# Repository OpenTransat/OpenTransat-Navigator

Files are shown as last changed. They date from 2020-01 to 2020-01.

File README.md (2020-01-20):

# OpenTransat-Navigator
The brain of the boat responsible for navigation.

## Features

* Based on Atmega2560 @ 16 MHz

* Over-the-air programming using ESP8266 flashed with Wifi-serial bridge [esp-link](https://github.com/jeelabs/esp-link)

* 9-axis accelerometer / gyro / compass

* Voltage / current sensor

* 16 Mbit flash

* 2 Mbit FRAM

* Temperature / pressure / humidity sensor

* Serial multiplexer

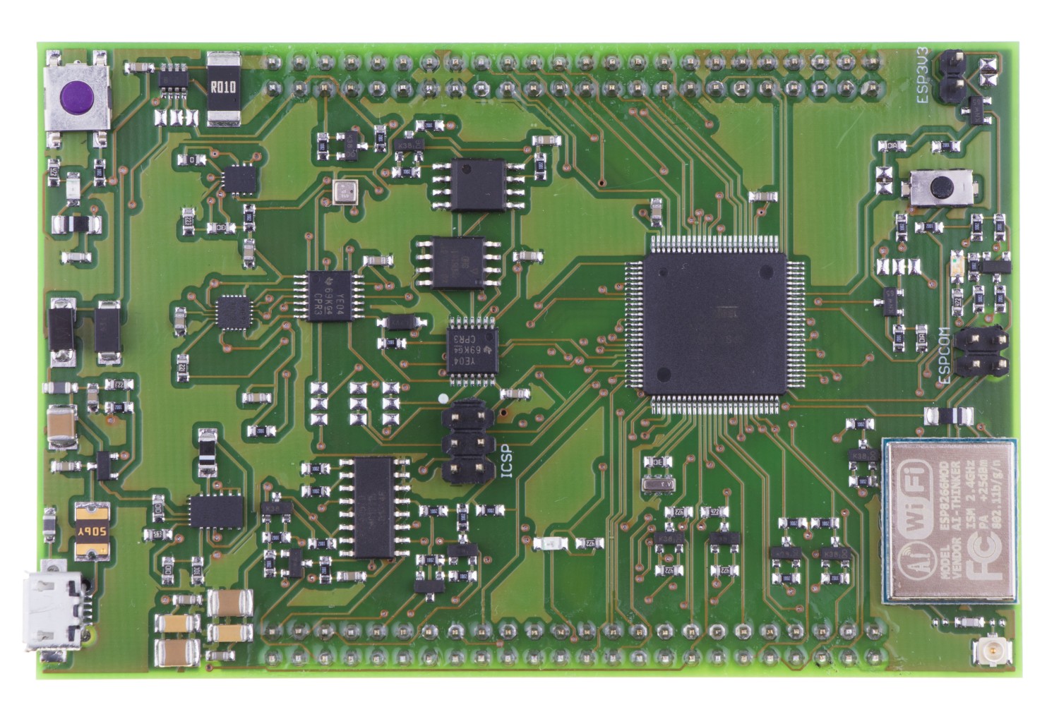
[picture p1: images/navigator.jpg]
Navigator PCB


## Boat Hardware Scheme

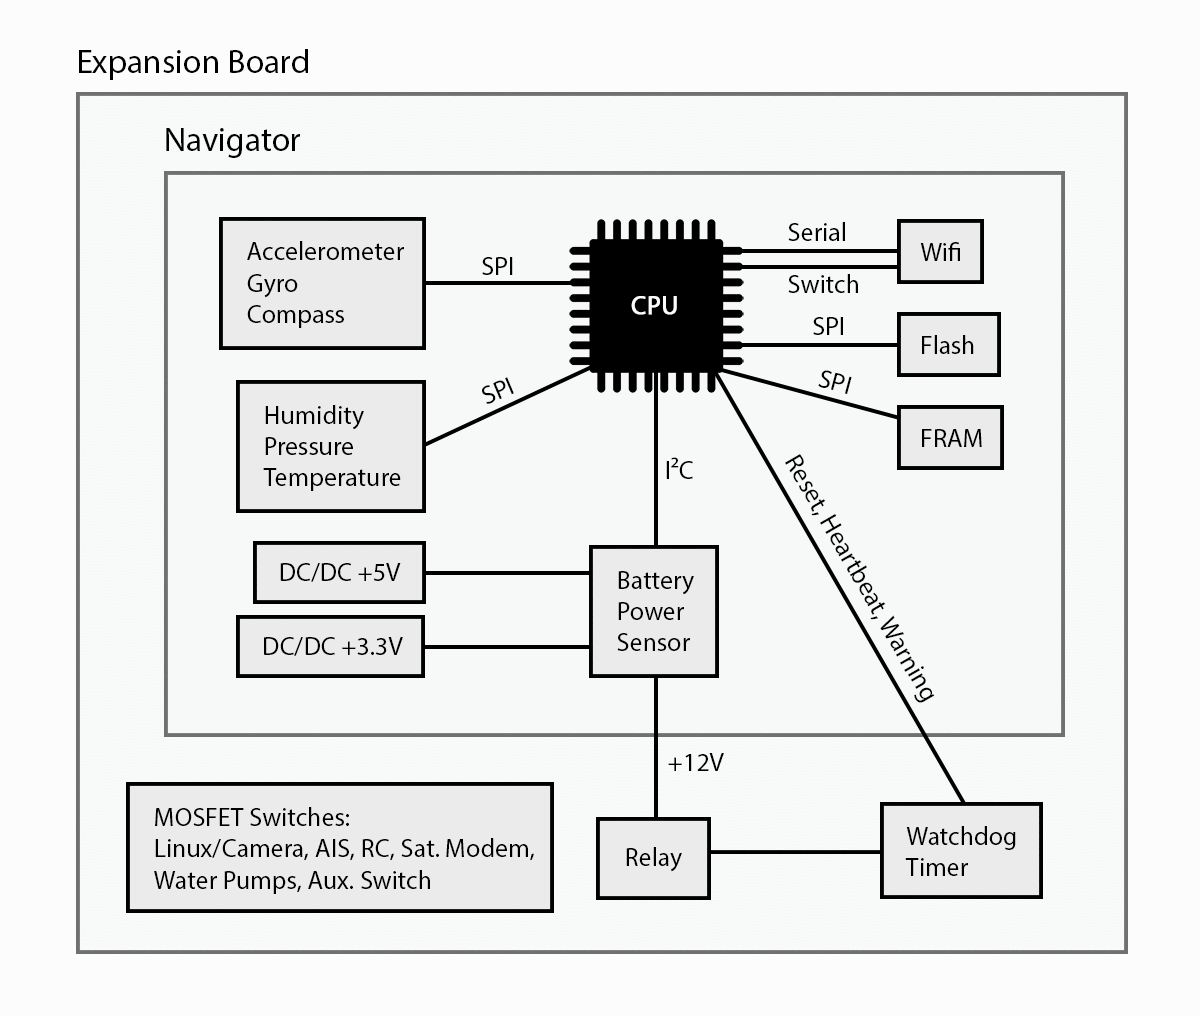
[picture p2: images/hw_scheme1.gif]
Boat Hardware Scheme


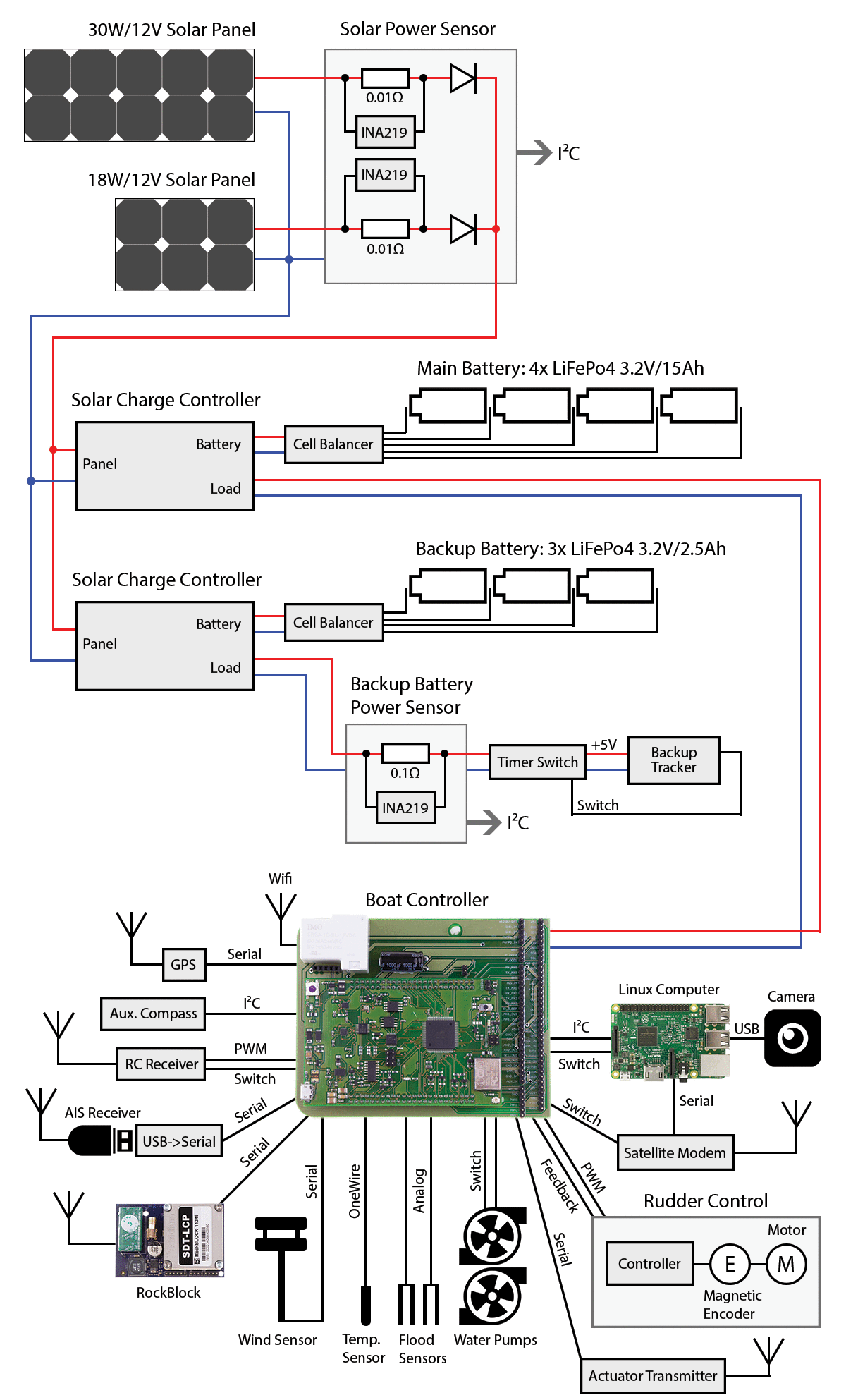
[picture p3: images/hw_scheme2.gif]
Boat Hardware Scheme


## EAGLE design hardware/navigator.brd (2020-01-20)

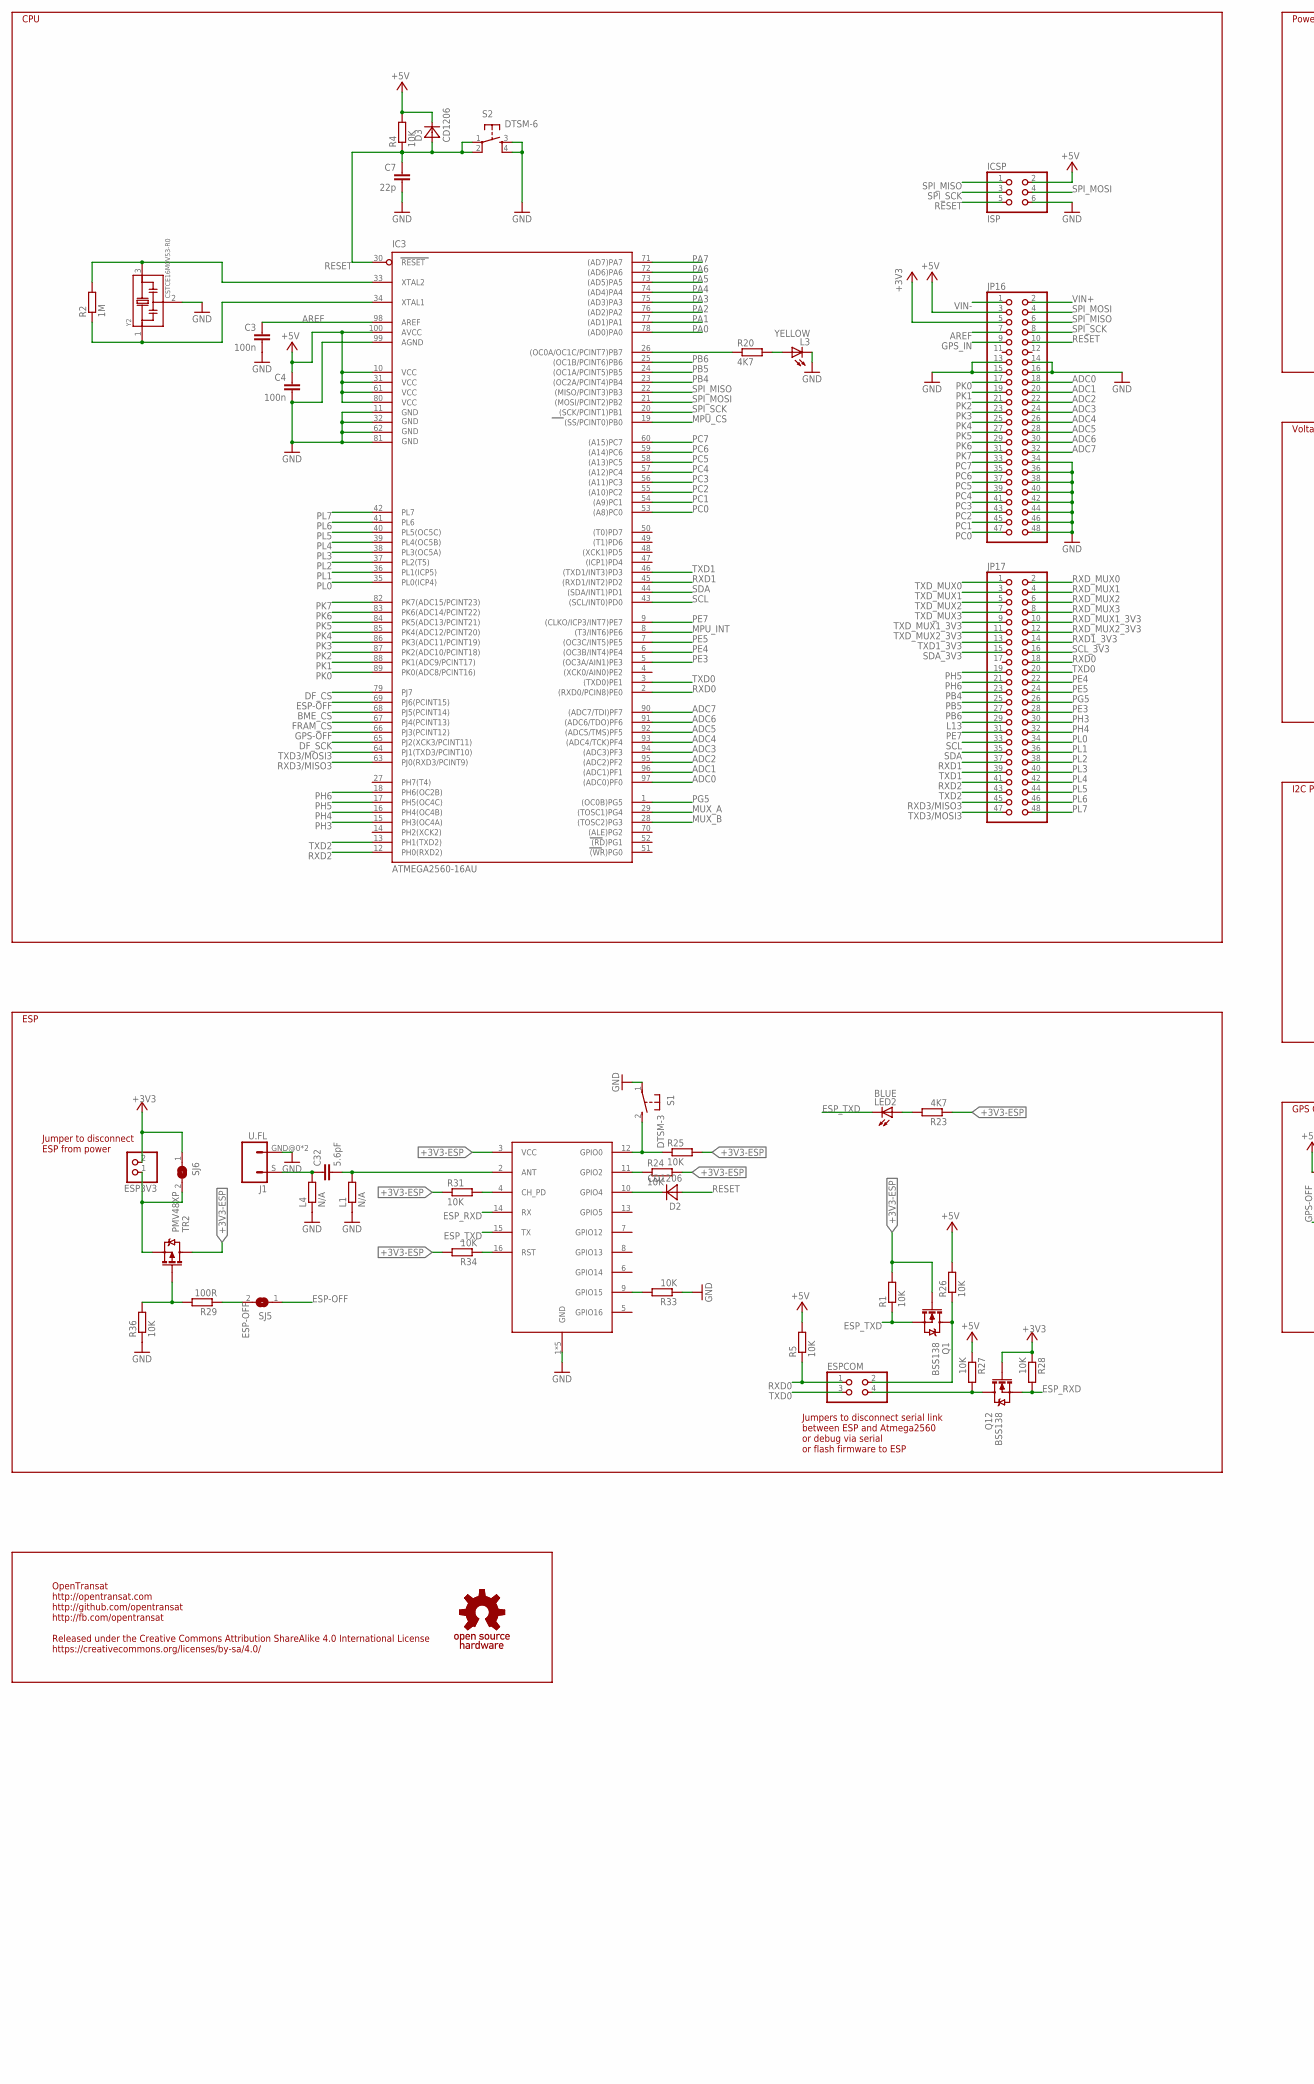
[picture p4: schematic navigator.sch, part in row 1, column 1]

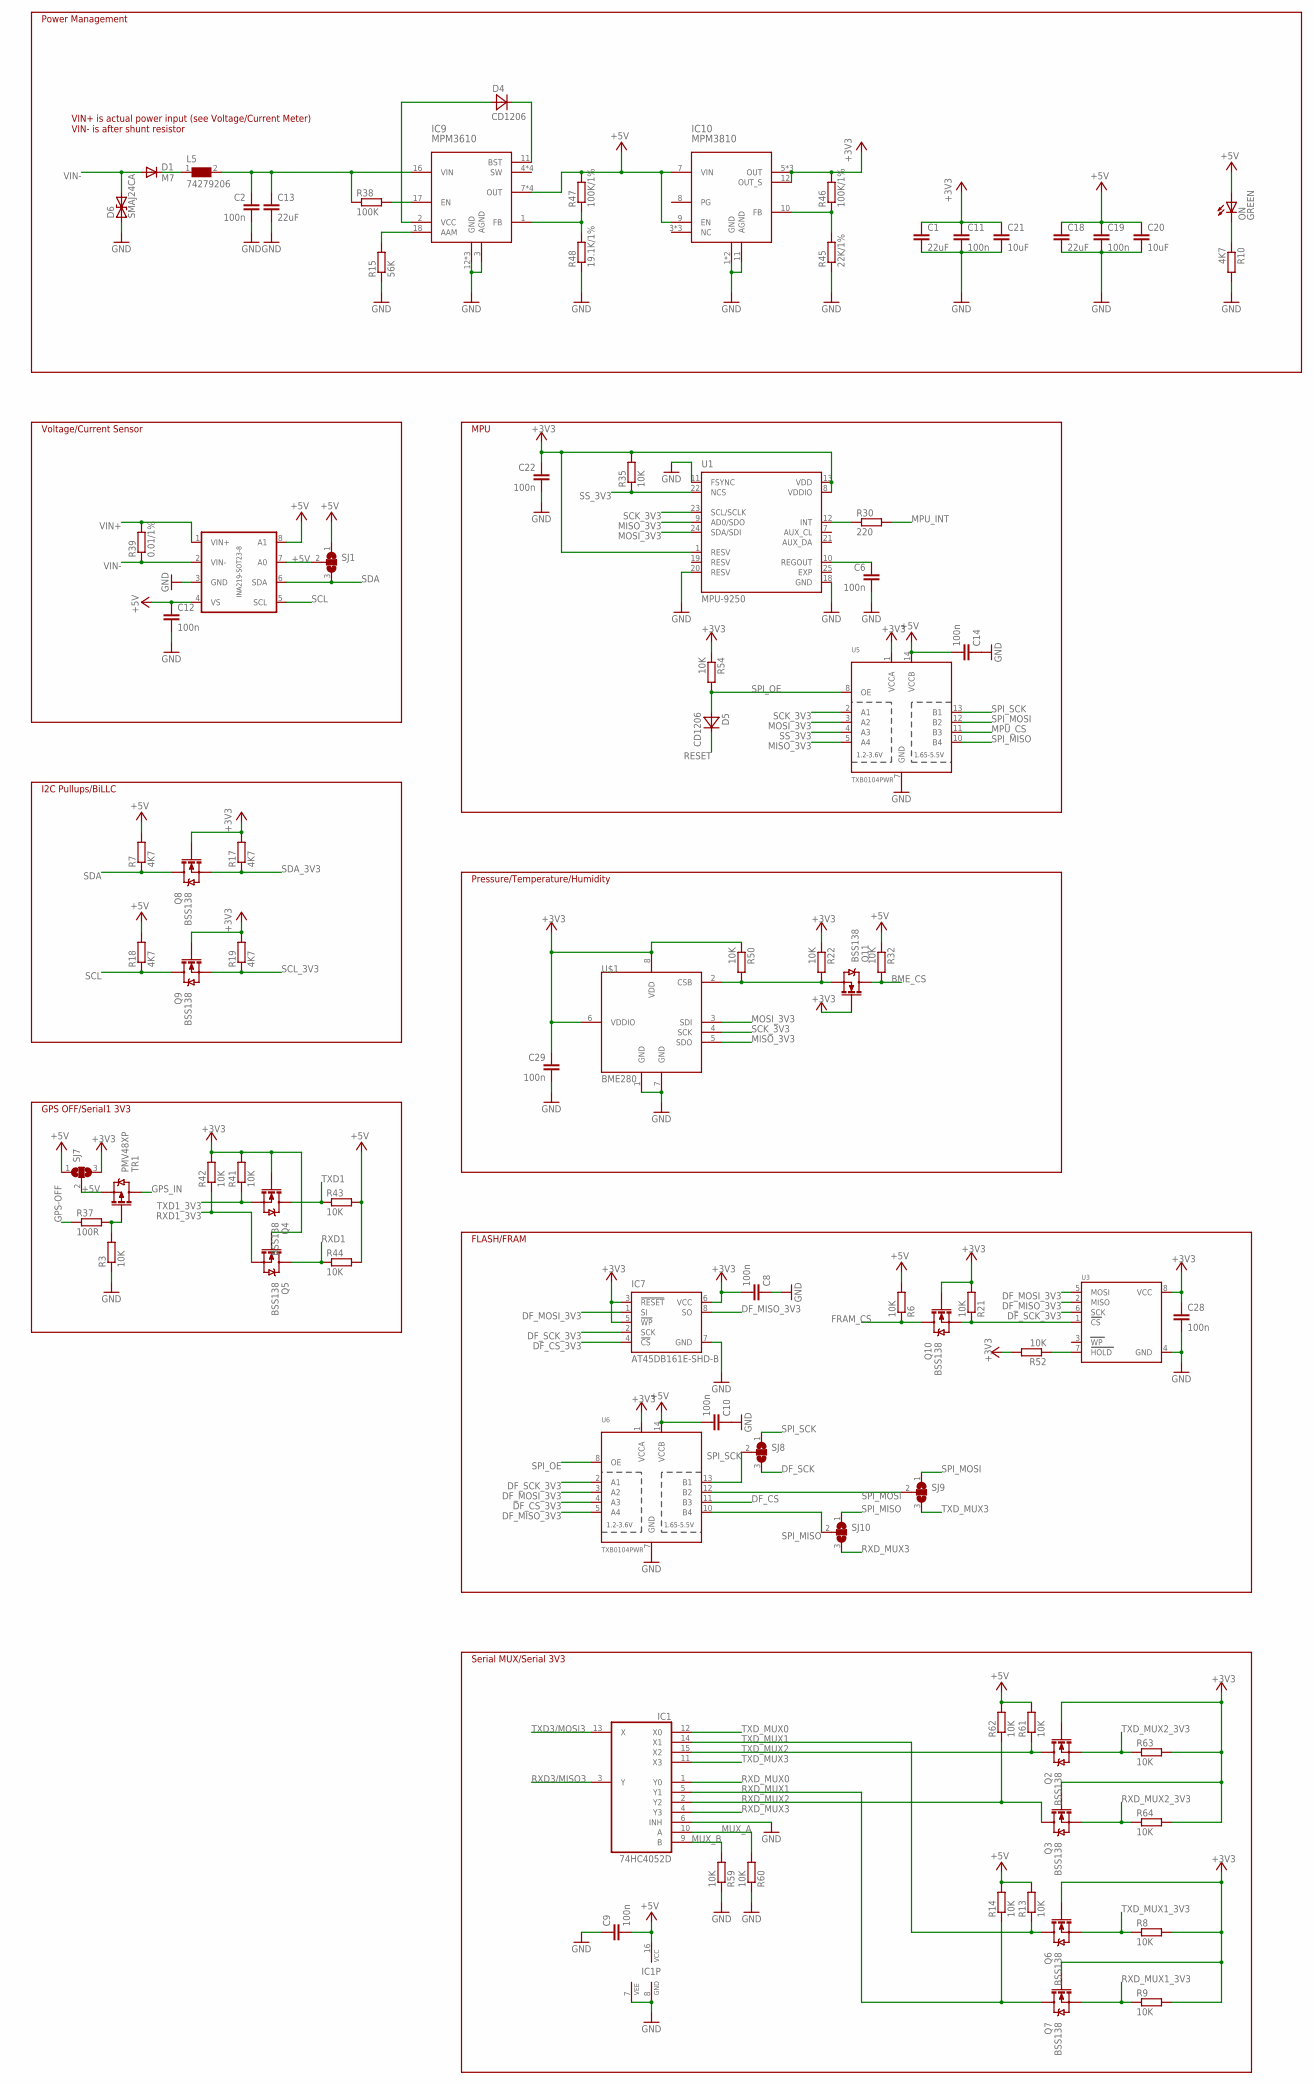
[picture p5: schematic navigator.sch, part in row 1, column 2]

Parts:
C1, C13, C18: 22uF; C1210
C2, C3, C4, C6, C8, C9, C10, C11, C12, C14, C19, C22, C28, C29: 100n; C0603
C7: 22p; C0603
C20, C21: 10uF; C1206
C32: 5.6pF; C0603
D1: M7; DO-214AC
D2, D3, D4, D5: CD1206; R1206
D6: SMAJ24CA; DO214AC
ESP3V3: PINHD-1X2; 1X02
ESPCOM: PINHD-2X2; 2X02
IC1: 74HC4052D; SO16
IC3: ATMEGA2560-16AU; TQFP100
IC7: AT45DB161E-SHD-B; 8S2
IC9: MPM3610; MPM_QFN20
IC10: MPM3810; MPM_QFN12
ICSP: ISP; 2X03
J1: U.FL; CON-U.FL
JP16, JP17: PINHD-2X24; 2X24
L1, L4: N/A; R0402
L3: YELLOW; CHIPLED_0805
L5: 74279206; 0805
LED2: BLUE; CHIPLED_0805
ON: GREEN; CHIPLED_0805
Q1, Q2, Q3, Q4, Q5, Q6, Q7, Q8, Q9, Q10, Q11, Q12: BSS138; SOT23-3
R1, R3, R4, R5, R6, R8, R9, R13, R14, R21, R22, R24, R25, R26, R27, R28, R31, R32, R33, R34, R35, R36, R41, R42, R43, R44, R50, R52, R54, R59, R60, R61, R62, R63, R64: 10K; R0603
R2: 1M; R0603
R7, R10, R17, R18, R19, R20, R23: 4K7; R0603
R15: 56K; R0603
R29, R37: 100R; R0603
R30: 220; R0603
R38: 100K; R0603
R39: 0.01/1%; R2512
R45: 22K/1%; R0603
R46, R47: 100K/1%; R0603
R48: 19.1K/1%; R0603
S1: DTSM-3
S2: DTSM-6
SJ1, SJ7, SJ8, SJ9, SJ10: SJ2W; SJ_2
SJ5, SJ6: SJ
TR1, TR2: PMV48XP; SOT23-3
U1: MPU-9250; QFN40P300X300X105-25N
U3: FRAM_SOIC8_200MIL_SPI; SOIC8_200MIL
U5, U6: TXB0104PWR; TSSOP14
U$1: BME280
U$2: ESP-06
U$3: INA219-SOT23-8; SOT23-8
U$4: OSHW; OSHWM
Y2: CSTCE16M0V53-R0; OSC_CSTCE16M0V53-R0

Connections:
+3V3: C1.1, C8.2, C11.1, C21.1, C22.1, C28.1, C29.1, ESP3V3.2, IC7.3 (!RESET), IC7.5 (!WP), IC7.6 (VCC), IC10.5 (OUT), IC10.6 (OUT), IC10.12 (OUT_S), IC10.14 (OUT), JP16.5, Q2.1 (G), Q3.1 (G), Q4.1 (G), Q5.1 (G), Q6.1 (G), Q7.1 (G), Q8.1 (G), Q9.1 (G), Q10.1 (G), Q11.1 (G), Q12.1 (G), R8.2, R9.2, R17.2, R19.2, R21.2, R22.1, R28.1, R35.2, R41.2, R42.2, R46.2, R50.1, R52.2, R54.1, R63.2, R64.2, SJ6.1, SJ7.3, U1.1 (RESV), U1.8 (VDDIO), U1.13 (VDD), U3.8 (VCC), U5.1 (VCCA), U6.1 (VCCA), U$1.6 (VDDIO), U$1.8 (VDD)
+3V3-ESP: Q1.1 (G), R1.2, R23.1, R24.2, R25.2, R31.1, R34.2, TR2.3 (D), U$2.3 (VCC)
+5V: C4.1, C9.2, C10.2, C12.1, C14.2, C18.1, C19.1, C20.1, D3.2 (C), IC1.16 (VCC), IC3.10 (VCC), IC3.31 (VCC1), IC3.61 (VCC2), IC3.80 (VCC3), IC3.100 (AVCC), IC9.7 (OUT), IC9.8 (OUT), IC9.9 (OUT), IC9.20 (OUT), IC10.7 (VIN), IC10.9 (EN), ICSP.2, JP16.3, ON.A, R4.2, R5.2, R6.2, R7.2, R13.2, R14.2, R18.2, R26.2, R27.1, R32.1, R43.2, R44.2, R47.2, R61.2, R62.2, SJ1.1, SJ1.2, SJ7.1, SJ7.2, TR1.2 (S), U5.14 (VCCB), U6.14 (VCCB), U$3.4 (VS), U$3.7 (A0), U$3.8 (A1)
ADC0: IC3.97 ((ADC0)PF0), JP16.18
ADC1: IC3.96 ((ADC1)PF1), JP16.20
ADC2: IC3.95 ((ADC2)PF2), JP16.22
ADC3: IC3.94 ((ADC3)PF3), JP16.24
ADC4: IC3.93 ((ADC4/TCK)PF4), JP16.26
ADC5: IC3.92 ((ADC5/TMS)PF5), JP16.28
ADC6: IC3.91 ((ADC6/TDO)PF6), JP16.30
ADC7: IC3.90 ((ADC7/TDI)PF7), JP16.32
AREF: C3.1, IC3.98 (AREF), JP16.7
BME_CS: IC3.68 (PJ5(PCINT14)), Q11.3 (D), R32.2
DF_CS: IC3.79 (PJ7), U6.11 (B3)
DF_CS_3V3: IC7.4 (!CS), U6.4 (A3)
DF_MISO_3V3: IC7.8 (SO), U3.2 (MISO), U6.5 (A4)
DF_MOSI_3V3: IC7.1 (SI), U3.5 (MOSI), U6.3 (A2)
DF_SCK: IC3.65 (PJ2(XCK3/PCINT11)), SJ8.3
DF_SCK_3V3: IC7.2 (SCK), U3.6 (SCK), U6.2 (A1)
ESP-OFF: IC3.69 (PJ6(PCINT15)), R29.1, SJ5.1, SJ5.2
ESP_RXD: Q12.2 (S), R28.2, U$2.14 (RX)
ESP_TXD: LED2.C, Q1.2 (S), R1.1, U$2.15 (TX)
EXP: U1.25 (EXP)
FRAM_CS: IC3.67 (PJ4(PCINT13)), Q10.3 (D), R6.1
GND: C1.2, C2.2, C3.2, C4.2, C6.2, C7.2, C8.1, C9.1, C10.1, C11.2, C12.2, C13.2, C14.1, C18.2, C19.2, C20.2, C21.2, C22.2, C28.2, C29.2, D6.A (1), IC1.6 (INH), IC1.7 (VEE), IC1.8 (GND), IC3.11 (GND), IC3.32 (GND1), IC3.62 (GND2), IC3.81 (GND3), IC3.99 (AGND), IC7.7 (GND), IC9.3 (AGND), IC9.12 (GND), IC9.13 (GND), IC9.14 (GND), IC10.1 (GND), IC10.2 (GND), IC10.11 (AGND), ICSP.6, J1.GND@0 (2), J1.GND@1 (2), JP16.13, JP16.14, JP16.15, JP16.16, JP16.34, JP16.36, JP16.38, JP16.40, JP16.42, JP16.44, JP16.46, JP16.48, L1.1, L3.C, L4.1, R3.1, R10.2, R15.1, R33.1, R36.1, R45.1, R48.1, R59.1, R60.1, S1.1, S2.3, S2.4, U1.11 (FSYNC), U1.18 (GND), U1.20 (RESV), U3.4 (GND), U5.7 (GND), U6.7 (GND), U$1.1 (GND), U$1.7 (GND), U$2.1 (GND), U$2.17 (GND), U$2.18 (GND), U$2.19 (GND), U$2.20 (GND), U$3.3 (GND), Y2.2
GPS-OFF: IC3.66 (PJ3(PCINT12)), R37.1
GPS_IN: JP16.9, TR1.3 (D)
L13: IC3.26 ((OC0A/OC1C/PCINT7)PB7), JP17.29, R20.1
MISO_3V3: U1.9 (AD0/SDO), U5.5 (A4), U$1.5 (SDO)
MOSI_3V3: U1.24 (SDA/SDI), U5.3 (A2), U$1.3 (SDI)
MPU_CS: IC3.19 ((SS/PCINT0)PB0), U5.11 (B3)
MPU_INT: IC3.8 ((T3/INT6)PE6), R30.2
MUX_A: IC1.10 (A), IC3.29 ((TOSC1)PG4), R60.2
MUX_B: IC1.9 (B), IC3.28 ((TOSC2)PG3), R59.2
unnamed: ESP3V3.1, SJ6.2, TR2.2 (S)
unnamed: R52.1, U3.7 (HOLD)
unnamed: ON.C, R10.1
unnamed: L3.A, R20.2
unnamed: D4.1 (A), IC9.2 (VCC)
unnamed: D4.2 (C), IC9.11 (BST)
unnamed: LED2.A, R23.2
unnamed: R31.2, U$2.4 (CH_PD)
unnamed: R24.1, U$2.11 (GPIO2)
unnamed: D2.2 (C), U$2.10 (GPIO4)
unnamed: R33.2, U$2.9 (GPIO15)
unnamed: C32.1, J1.S (1), L4.2
unnamed: R25.1, S1.2, U$2.12 (GPIO0)
unnamed: R34.1, U$2.16 (RST)
unnamed: C32.2, L1.2, U$2.2 (ANT)
unnamed: Q10.2 (S), R21.1, U3.1 (CS)
unnamed: IC10.10 (FB), R45.2, R46.1
unnamed: ESPCOM.2, Q1.3 (D), R26.1
unnamed: ESPCOM.4, Q12.3 (D), R27.2
unnamed: R3.2, R37.2, TR1.1 (G)
unnamed: R29.2, R36.2, TR2.1 (G)
unnamed: IC9.1 (FB), R47.1, R48.2
unnamed: IC9.17 (EN), R38.2
unnamed: IC9.18 (AAM), R15.2
unnamed: Q11.2 (S), R22.2, R50.2, U$1.2 (CSB)
unnamed: R30.1, U1.12 (INT)
PA0: IC3.78 ((AD0)PA0)
PA1: IC3.77 ((AD1)PA1)
PA2: IC3.76 ((AD2)PA2)
PA3: IC3.75 ((AD3)PA3)
PA4: IC3.74 ((AD4)PA4)
PA5: IC3.73 ((AD5)PA5)
PA6: IC3.72 ((AD6)PA6)
PA7: IC3.71 ((AD7)PA7)
PB4: IC3.23 ((OC2A/PCINT4)PB4), JP17.23
PB5: IC3.24 ((OC1A/PCINT5)PB5), JP17.25
PB6: IC3.25 ((OC1B/PCINT6)PB6), JP17.27
PC0: IC3.53 ((A8)PC0), JP16.47
PC1: IC3.54 ((A9)PC1), JP16.45
PC2: IC3.55 ((A10)PC2), JP16.43
PC3: IC3.56 ((A11)PC3), JP16.41
PC4: IC3.57 ((A12)PC4), JP16.39
PC5: IC3.58 ((A13)PC5), JP16.37
PC6: IC3.59 ((A14)PC6), JP16.35
PC7: IC3.60 ((A15)PC7), JP16.33
PE3: IC3.5 ((OC3A/AIN1)PE3), JP17.28
PE4: IC3.6 ((OC3B/INT4)PE4), JP17.22
PE5: IC3.7 ((OC3C/INT5)PE5), JP17.24
PE7: IC3.9 ((CLKO/ICP3/INT7)PE7), JP17.31
PG5: IC3.1 ((OC0B)PG5), JP17.26
PH3: IC3.15 (PH3(OC4A)), JP17.30
PH4: IC3.16 (PH4(OC4B)), JP17.32
PH5: IC3.17 (PH5(OC4C)), JP17.19
PH6: IC3.18 (PH6(OC2B)), JP17.21
PK0: IC3.89 (PK0(ADC8/PCINT16)), JP16.17
PK1: IC3.88 (PK1(ADC9/PCINT17)), JP16.19
PK2: IC3.87 (PK2(ADC10/PCINT18)), JP16.21
PK3: IC3.86 (PK3(ADC11/PCINT19)), JP16.23
PK4: IC3.85 (PK4(ADC12/PCINT20)), JP16.25
PK5: IC3.84 (PK5(ADC13/PCINT21)), JP16.27
PK6: IC3.83 (PK6(ADC14/PCINT22)), JP16.29
PK7: IC3.82 (PK7(ADC15/PCINT23)), JP16.31
PL0: IC3.35 (PL0(ICP4)), JP17.34
PL1: IC3.36 (PL1(ICP5)), JP17.36
PL2: IC3.37 (PL2(T5)), JP17.38
PL3: IC3.38 (PL3(OC5A)), JP17.40
PL4: IC3.39 (PL4(OC5B)), JP17.42
PL5: IC3.40 (PL5(OC5C)), JP17.44
PL6: IC3.41 (PL6), JP17.46
PL7: IC3.42 (PL7), JP17.48
PWRIN2: D1.C, L5.1
REGOUT: C6.1, U1.10 (REGOUT)
RESET: C7.1, D2.1 (A), D3.1 (A), D5.2 (C), IC3.30 (RESET), ICSP.5, JP16.10, R4.1, S2.1, S2.2
RESV: U1.19 (RESV)
RXD0: ESPCOM.1, IC3.2 ((RXD0/PCIN8)PE0), JP17.18, R5.1
RXD1: IC3.45 ((RXD1/INT2)PD2), JP17.37, Q5.3 (D), R44.1
RXD1_3V3: JP17.14, Q5.2 (S), R42.1
RXD2: IC3.12 (PH0(RXD2)), JP17.41
RXD3/MISO3: IC1.3 (Y), IC3.63 (PJ0(RXD3/PCINT9)), JP17.45
RXD_MUX0: IC1.1 (Y0), JP17.2
RXD_MUX1: IC1.5 (Y1), JP17.4, Q7.3 (D), R14.1
RXD_MUX1_3V3: JP17.10, Q7.2 (S), R9.1
RXD_MUX2: IC1.2 (Y2), JP17.6, Q3.3 (D), R62.1
RXD_MUX2_3V3: JP17.12, Q3.2 (S), R64.1
RXD_MUX3: IC1.4 (Y3), JP17.8, SJ10.3
SCK_3V3: U1.23 (SCL/SCLK), U5.2 (A1), U$1.4 (SCK)
SCL: IC3.43 ((SCL/INT0)PD0), JP17.33, Q9.3 (D), R18.1, U$3.5 (SCL)
SCL_3V3: JP17.16, Q9.2 (S), R19.1
SDA: IC3.44 ((SDA/INT1)PD1), JP17.35, Q8.3 (D), R7.1, SJ1.3, U$3.6 (SDA)
SDA_3V3: JP17.15, Q8.2 (S), R17.1
SPI_MISO: IC3.22 ((MISO/PCINT3)PB3), ICSP.1, JP16.6, SJ10.1, SJ10.2, U5.10 (B4), U6.10 (B4)
SPI_MOSI: IC3.21 ((MOSI/PCINT2)PB2), ICSP.4, JP16.4, SJ9.1, SJ9.2, U5.12 (B2), U6.12 (B2)
SPI_OE: D5.1 (A), R54.2, U5.8 (OE), U6.8 (OE)
SPI_SCK: IC3.20 ((SCK/PCINT1)PB1), ICSP.3, JP16.8, SJ8.1, SJ8.2, U5.13 (B1), U6.13 (B1)
SS_3V3: R35.1, U1.22 (NCS), U5.4 (A3)
TXD0: ESPCOM.3, IC3.3 ((TXD0)PE1), JP17.20
TXD1: IC3.46 ((TXD1/INT3)PD3), JP17.39, Q4.3 (D), R43.1
TXD1_3V3: JP17.13, Q4.2 (S), R41.1
TXD2: IC3.13 (PH1(TXD2)), JP17.43
TXD3/MOSI3: IC1.13 (X), IC3.64 (PJ1(TXD3/PCINT10)), JP17.47
TXD_MUX0: IC1.12 (X0), JP17.1
TXD_MUX1: IC1.14 (X1), JP17.3, Q6.3 (D), R13.1
TXD_MUX1_3V3: JP17.9, Q6.2 (S), R8.1
TXD_MUX2: IC1.15 (X2), JP17.5, Q2.3 (D), R61.1
TXD_MUX2_3V3: JP17.11, Q2.2 (S), R63.1
TXD_MUX3: IC1.11 (X3), JP17.7, SJ9.3
VIN: C2.1, C13.1, IC9.16 (VIN), L5.2, R38.1
VIN+: JP16.2, R39.2, U$3.1 (VIN+)
VIN-: D1.A, D6.C (2), JP16.1, R39.1, U$3.2 (VIN-)
XTAL1: IC3.34 (XTAL1), R2.1, Y2.1
XTAL2: IC3.33 (XTAL2), R2.2, Y2.3

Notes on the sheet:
Serial MUX/Serial 3V3
Voltage/Current Sensor
GPS OFF/Serial1 3V3
FLASH/FRAM
MPU
Pressure/Temperature/Humidity
ESP
CPU
Power Management
I2C Pullups/BiLLC
VIN+ is actual power input (see Voltage/Current Meter) VIN- is after shunt resistor
OpenTransat http://opentransat.com http://github.com/opentransat http://fb.com/opentransat Released under the Creative Commons Attribution ShareAlike 4.0 International License https://creativecommons.org/licenses/by-sa/4.0/
Jumper to disconnect ESP from power
Jumpers to disconnect serial link between ESP and Atmega2560 or debug via serial or flash firmware to ESP

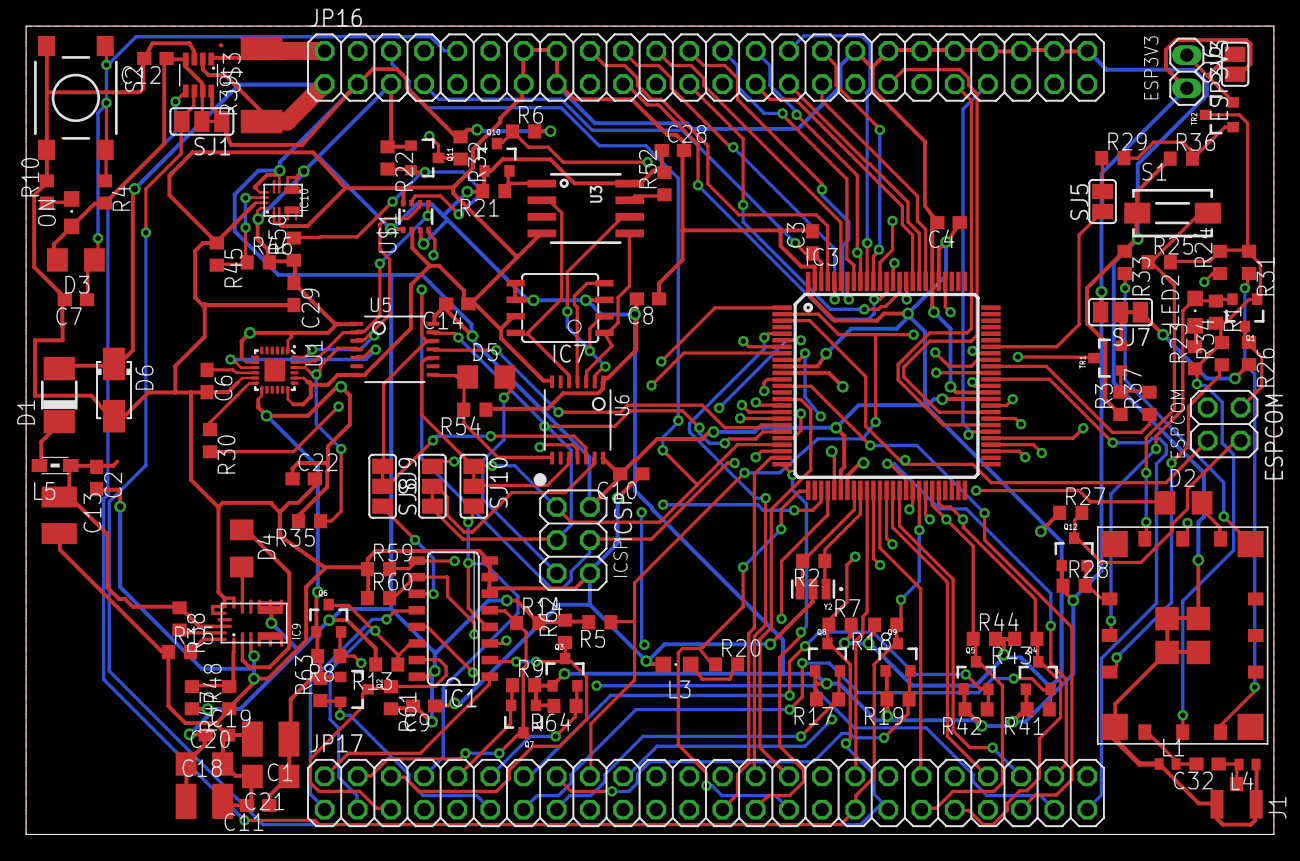
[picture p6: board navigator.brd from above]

Board: 4 copper layers, 95.6 x 61.9 mm, 129 parts (0 on the bottom side), 135 nets.

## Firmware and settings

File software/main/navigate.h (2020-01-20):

#define NAVMODE_MANUAL 0
#define NAVMODE_RUDDER_AUTO 1
#define NAVMODE_FLAP_AUTO 2
#define NAVMODE_FULLY_AUTO 3

#define TACKMODE_DIRECTLY 0
#define TACKMODE_ADJ_POS 1
#define TACKMODE_ADJ_NEG 2
#define TACKMODE_MAXDEV_POS 3
#define TACKMODE_MAXDEV_NEG 4

#define DEFAULT_RUDDER_COEFF 40
#define DEFAULT_RUDDER_PAUSE_SEC 2 //in seconds
#define RUDDER_MIN_ANGLE -25
#define RUDDER_MAX_ANGLE 25

#define HEADING_OK_LIMIT 7 //in degs

#define FLAP_MAX 16
#define FLAP_NORMAL 10
#define TACK_SAIL_CRITICAL_ANGLE 7
#define WIND_CONFIRMATION_SEC 3

//Earth mean radius
#define R_MEAN 6371000.0 //meters

//how often the magnetic declination is updated
#define MAGDEC_UPDATE_DISTANCE 100000.0 //meters
#define INTENSIVE_TASKS_INTERVAL 30000UL //30sec (function lasts: 14ms)

//#define ACT_MUST_WAIT_FROM_LNG -52.8943 //prevent waiting during launch //not used, rather use LAUNCH_DATE
#define ACT_LAUNCH_DATE 80719UL //MMDDYYUL, no leading zero

struct Location {
  double lat;
  double lng;
};

struct {
  unsigned char mode = NAVMODE_FULLY_AUTO;
  unsigned char tackmode = TACKMODE_DIRECTLY;
  Location gps;
  float magDec; //in degs
  bool magDecInitialized = false; //magDec is initialized based on valid gps location before the boat can navigate
  bool intensiveTasks_initialized = false; //ghostPoint must be calculated before the boat can navigate
  bool ghostHeadingInitialized = false; //ghostHeading must be calculated before the boat can navigate
  Location magDec_loc; //last location where magDec was calculated
  bool IR_doTransmit = false; //this flag is set to true in Iridium interval and transmitting starts in the navigate(..) function when the rudder is idle for a moment
  int trueHeading; //compass yaw + magnetic declination
  int trueWind; //trueHeading + relative wind
  Location closestPoint;
  Location ghostPoint;
  double crossTrack;
  double alongTrack;
  int ghostHeading_instant; //heading to the ghostPoint
  int ghostHeading; //heading to the ghostPoint (if headingOK())
  int goHeading; //in degs, where to go
  int pathAngle; //path bearing at closestPoint
  bool isBehindPath;
  int error; //in degs
  int flap;
  int sail_angle;
  int rudder_angle = 0; //must be remembered after the navigate() iteration
  bool rudderAgainstWind; //if the default turning is against the wind
  bool IR_transmit = false;
  unsigned long intensive_ms = 0;
  unsigned long nonIntensive_micros = 0;
  char wind_confirmation_sec = WIND_CONFIRMATION_SEC;
} nav;

struct TadjustedAngles {
  bool canGoDirectly;
  int adjAngle1;
  int adjAngle2;
};

struct TbestAdjHeading {
  int heading;
  unsigned char tackmode;
};

//location with radius[meters]; waypoint is considered to be reached within the radius, boat is heading to the ghostPoint at ghostDistance and special consideration is taken if max deviation from the main path is reached
struct waypoint {
  Location loc;
  double radius;
  double ghostDistance;
  double maxDev;
};

#define MAXDEV_OK_FACTOR 0.75

//Newfoundland -> waypoint on finish line -> Brest
//set of waypoints
#define WAYPOINTS 4 //minimum 2: (start, finish}
#define FINISH_WAYPOINT 3

//loc, radius, ghostDistance, maxDev

waypoint path[WAYPOINTS] = {
  {{46.913520, -52.998886}, 0.0, 0.0, 0.0}, //Newfoundland
  {{46.75, -47.0}, 50000.0, 50000.0, 50000.0}, //on the start line, 139km below the north endpoint
  {{46.75, -46.34}, 50000.0, 50000.0, 50000.0}, //50km east from the previous point (to make sure to cross the start line)
  {{48.0, -13.0}, 20000.0, 75000.0, 75000.0}, //finish line (also update FINISH_WAYPOINT macro, indexing starts from 0)
};
/*
waypoint path[WAYPOINTS] = { //!!!ONLY FOR SIMULATION, COMMENT FOR REAL MISSION
  {{46.913520, -52.998886}, 0.0, 0.0, 0.0}, //Newfoundland
  {{46.75, -47.0}, 70000.0, 250000.0, 250000.0}, //on the start line, 139km below the north endpoint
  {{46.75, -46.34}, 70000.0, 250000.0, 250000.0}, //50km east from the previous point (to make sure to cross the start line)
  {{48.0, -13.0}, 70000.0, 500000.0, 500000.0}, //finish line (also update FINISH_WAYPOINT macro, indexing starts from 0)
};
*/
#define SIM_MAX_SPEED 2000000.0
#define SIM_RUDDER_RESPONSE 0.00005

struct {
  bool active = false;
  bool pause = false;
  int trueHeading = 0;
  double trueHeading_f = 0; //sim_move()
  int trueWind = 0;
  Location gps = path[0].loc;
  int rudder_angle = 0;
  int flap = FLAP_NORMAL;
  int adjAngle1;
  int adjAngle2;
  double max_speed = SIM_MAX_SPEED;
  double rudder_response = SIM_RUDDER_RESPONSE;
} sim;

struct {
} sim_debug;

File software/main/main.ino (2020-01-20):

/*
Main Controller

OpenTransat
http://opentransat.com
http://github.com/opentransat
http://fb.com/opentransat
Released under the Creative Commons Attribution ShareAlike 4.0 International License
https://creativecommons.org/licenses/by-sa/4.0/
*/

#include <Wire.h>
#include <SPI.h>
#include <MPU9250.h>
#include <Adafruit_INA219.h>
#include <Adafruit_FRAM2Mbit_SPI.h>
#include <DataFlash.h>
#include <Adafruit_Sensor.h>
#include <Adafruit_BME280.h>
#include <TinyGPS++.h>
#include <OneWire.h>
#include <IridiumSBD.h>
#include <SoftwareSerial.h>
#include <EEPROM.h>
#include <avr/pgmspace.h>

#include "pins.h";
#include "rc.h";
#include "sensors.h";
#include "actuator.h";
#include "comms.h";
#include "log.h";
#include "declination.h";
#include "navigate.h";
#include "memory.h";
#include "camera.h";

//#define SERIAL_DEBUG //comment for real mission
//#define IGNORE_IRIDIUM //comment for real mission
//#define USE_RC //comment for real mission

#ifdef SERIAL_DEBUG
  #define debug(x) if (!sim.active) Serial.print(x)
  #define debugln(x) if (!sim.active) Serial.println(x)
  #define debug2(x, y) if (!sim.active) Serial.print((x), (y))
  #define debugln2(x, y) if (!sim.active) Serial.println((x), (y))
  #define debugWrite(x) if (!sim.active) Serial.write(x)
#else
  #define debug(x) noDebug()
  #define debugln(x) noDebug()
  #define debug2(x, y) noDebug()
  #define debugln2(x, y) noDebug()
  #define debugWrite(x) noDebug()
#endif

#define BAUD_SERIAL0 115200
#define BAUD_GPS 9600
#define BAUD_CAM 4800
#define BAUD_IR 19200
#define BAUD_RUDDER_HALL 9600
#define BAUD_AIS 38400 //or configure to 9600
#define BAUD_ANEMO 4800
#define BAUD_ACT 9600
#define BAUD_COMPASS 38400
#define FLOOD_THRESHOLD 700
#define GPS_HDOP_THRESHOLD 20

DataFlash dataflash;
Adafruit_FRAM_SPI fram = Adafruit_FRAM_SPI(FRAM_CS);  // use hardware SPI
SoftwareSerial camSerial(CAM_RX, CAM_TX); //RX, TX
SoftwareSerial rudderSerial(RUDDER_RX, RUDDER_TX); //RX, TX

#define MUX_GPS 0
#define MUX_IR 1
#define MUX_ACT 2
#define MUX_AIS 3

//ext led blinking
#define WORD(hb, lb) (((unsigned int)(hb) << 8) + (lb))
#define BLINK_STARTUP WORD(1, 1) //before GPS location
#define BLINK_GPS WORD(2, 2) //GPS location
#define BLINK_HEADING WORD(3, 3) //GPS location && correct heading 
#define BLINK_IRIDIUM WORD(4, 4) //transmitting via Iridium
#define BLINK_ACT WORD(2, 1) //actuator: waiting for response
#define BLINK_STOP_LNG_FROM -52.6
#define BLINK_STOP_LNG_TO -4.544

unsigned int blinkMode = BLINK_STARTUP;

//intervals
#define HEARTBEAT_INDEX 0
#define BLINK_INDEX 1
#define DEBUG_INDEX 2
#define VAMPS_INDEX 3
#define RUDDER_INDEX 4
#define IR_INDEX 5
#define LOG_INDEX 6
#define SIM_MOVE_INDEX 7
#define SIM_PRINT_INDEX 8
#define HEARTBEAT_INTERVAL 1000UL
#define BLINK_ON_INTERVAL 20UL
#define BLINK_PAUSE1_INTERVAL 500UL
#define BLINK_PAUSE2_INTERVAL 1500UL
#define DEBUG_INTERVAL 1000UL
#define VAMPS_INTERVAL 1000UL
#define RUDDER_INTERVAL 20UL
#define IR_STARTUP_INTERVAL 180000UL //3min after startup
#define IR_NORMAL_INTERVAL 3600000UL //60min normally
#define IR_URGENT_INTERVAL 600000UL //10min after being ignored or cancelled because of more important tasks (actuator)
#define LOG_INTERVAL 1800000UL //30min log
#define SIM_MOVE_INTERVAL 1UL
#define SIM_PRINT_INTERVAL 10UL
unsigned long intervals[] = {HEARTBEAT_INTERVAL, BLINK_PAUSE2_INTERVAL, DEBUG_INTERVAL, VAMPS_INTERVAL, RUDDER_INTERVAL, IR_STARTUP_INTERVAL, LOG_INTERVAL, SIM_MOVE_INTERVAL, SIM_PRINT_INTERVAL};
unsigned long setInterval_previousMillis[] = {0, 0, 0, 0, 0, 0, 0, 0, 0};

#define SAIL_STATE_IDLE 0
#define SAIL_STATE_WAIT_DATA 1
#define SAIL_STATE_WAIT_A 2
#define SAIL_STATE_WAIT_PE 3
#define SAIL_STATE_NEW_DATA 4
#define SAIL_STATE_NEW_A 5
#define SAIL_STATE_NEW_P 6
#define SAIL_STATE_NEW_E 7

#define SAIL_MAX_RETRIES 15
//#define SAIL_MAX_RETRIES 5 //testing

#define SAIL_TIMEOUT_DATA 10000UL
#define SAIL_TIMEOUT_A 7000UL
#define SAIL_TIMEOUT_PE 20000UL
#define SAIL_MAX_RETRIES_WAIT_PERIOD 1800000UL //30min
//#define SAIL_MAX_RETRIES_WAIT_PERIOD 60000UL //1min //testing

unsigned long sail_start_ms = 0;
char sail_state = SAIL_STATE_IDLE;
int sail_retries = 0;
bool sail_max_retries_wait = false;
unsigned long sail_max_retries_wait_ms = 0;

void (*saildata_callback_success)();
void (*saildata_callback_timeout)();

#define REL_WIND(SAIL_ANGLE, FLAP_ANGLE) mod360((int)(SAIL_ANGLE) + (int)(FLAP_ANGLE))

bool cancel_iridium = false;
char mux;

void setMUX(char x) {
  mux = x; // global var
  digitalWrite(MUX_A, bitRead(x, 0));
  digitalWrite(MUX_B, bitRead(x, 1));
}

struct {
  unsigned char pulse = 100; //100 +- angle
  char feedback;
  unsigned long last_update;
  unsigned long count = 0;
  unsigned long pause_start = 0;
} rudder;

void init_io() {
  pinMode(IR_SLEEP, OUTPUT);
  digitalWrite(IR_SLEEP, LOW); //Iridium sleeps @ LOW

  pinMode(HEARTBEAT, OUTPUT);
  digitalWrite(HEARTBEAT, LOW);
  
  pinMode(WARNING, INPUT); //active LOW
  
  pinMode(MPU_INT, INPUT);
  
  pinMode(LED, OUTPUT);
  digitalWrite(LED, LOW);
  
  pinMode(ESP_OFF, OUTPUT);
  digitalWrite(ESP_OFF, LOW); //ESP active @ LOW
  
  pinMode(GPS_OFF, OUTPUT);
  digitalWrite(GPS_OFF, LOW); //GPS active @ LOW

  pinMode(ACT_ON, OUTPUT);
  digitalWrite(ACT_ON, LOW); //active HIGH

  pinMode(HALL_ON, OUTPUT);
  digitalWrite(HALL_ON, HIGH); //active HIGH

  pinMode(LED_EXT, OUTPUT);
  digitalWrite(LED_EXT, LOW);

  pinMode(PWRSENSOR_ON, OUTPUT);
  digitalWrite(PWRSENSOR_ON, LOW); //active HIGH

  //mosfets
  pinMode(CAM_ON, OUTPUT);
  digitalWrite(CAM_ON, LOW); //active HIGH
  
  pinMode(SAT_ON, OUTPUT);
  digitalWrite(SAT_ON, LOW); //active HIGH
  
  pinMode(AUX_ON, OUTPUT);
  digitalWrite(AUX_ON, LOW); //active HIGH
  
  pinMode(PUMP1_ON, OUTPUT);
  digitalWrite(PUMP1_ON, LOW); //active HIGH
  
  pinMode(PUMP2_ON, OUTPUT);
  digitalWrite(PUMP2_ON, LOW); //active HIGH
  
  pinMode(AIS_OFF, OUTPUT);
  digitalWrite(AIS_OFF, HIGH); //active LOW
  
  pinMode(RC_OFF, OUTPUT);

  #ifdef USE_RC
    digitalWrite(RC_OFF, LOW); //active LOW
  #else
    digitalWrite(RC_OFF, HIGH); //active LOW
  #endif
  
  //MUX
  pinMode(MUX_A, OUTPUT);
  digitalWrite(MUX_A, LOW);
  
  pinMode(MUX_B, OUTPUT);
  digitalWrite(MUX_B, LOW);

  //onboard stuff
  pinMode(MPU_CS, OUTPUT);
  digitalWrite(MPU_CS, HIGH);

  pinMode(BME_CS, OUTPUT);
  digitalWrite(BME_CS, HIGH);

  pinMode(FRAM_CS, OUTPUT);
  digitalWrite(FRAM_CS, HIGH);
  
  pinMode(DF_CS, OUTPUT);
  digitalWrite(DF_CS, HIGH);

  //RC
  pinMode(RC_PWM0, INPUT_PULLUP);
  pinMode(RC_PWM1, INPUT_PULLUP);
  pinMode(RC_PWM2, INPUT_PULLUP);
  pinMode(RC_PWM3, INPUT_PULLUP);
}

void setup() {
  init_io();
  Serial.begin(BAUD_SERIAL0);
  Wire.begin();

  debugln(F("--------- start ---------------"));

  SPI.begin();

  //MPU
  MPU_init();

  //BME
  BME_init();

  //Iridium
  IR_init();

  //Remote Control
  #ifdef USE_RC
    RC_init();
  #endif

  //FRAM
  FRAM_init();
  
//  test_FRAM();

  //DataFlash

//  test_DataFlash();

  Serial1.begin(BAUD_RUDDER_HALL); //RUDDER TX and HALL RX
  Serial2.begin(BAUD_COMPASS); //compass
  Serial3.begin(BAUD_GPS);
  setMUX(MUX_GPS); //default: GPS whenever possible

  anemoSerial.begin(BAUD_ANEMO);
  
  rudderSerial.begin(BAUD_RUDDER_HALL);

  saildata_callback_success = printData2; //make sure it's initialized
  saildata_callback_timeout = printData2; //make sure it's initialized

  sail.hall_update = millis();
  rudder.pause_start = millis();

  eeLoad();
  ee.resets++;
  eeSave(SAVE_REASON_RESETS);
}

void loop() {
  setInterval(HEARTBEAT_INDEX);
  setInterval(BLINK_INDEX);
  setInterval(VAMPS_INDEX);
  setInterval(RUDDER_INDEX);
  setInterval(IR_INDEX);
  setInterval(DEBUG_INDEX);
  setInterval(LOG_INDEX);
  
  checkSailResponse();

  camera();
  countCapsize();
  checkCompass();
  checkHall();
  act.mustWait = actMustWait();

  navigate1();

  if (sim.active) {
    setInterval(SIM_MOVE_INDEX);
    setInterval(SIM_PRINT_INDEX);
  }
  
  smartDelay(0); //read and process all serial inputs

  #ifdef SERIAL_DEBUG
    readcmd();
  #endif
}

bool ISBDCallback() { //fires multiple times while Iridium is sending message, can be cancelled by cancel_iridium from switchAct()
  setInterval(HEARTBEAT_INDEX);
  setInterval(BLINK_INDEX);
  setInterval(VAMPS_INDEX);
  setInterval(RUDDER_INDEX);
  //setInterval(IR_INDEX); //do not call while transmitting
  setInterval(DEBUG_INDEX);
  setInterval(LOG_INDEX);
  
  //checkSailResponse(); //do not call, we are not expecting a response from the sailwing while sending a message (Serial3 is muxed to Iridium)

  camera();
  countCapsize();
  checkCompass();
  checkHall();
  act.mustWait = actMustWait();

  navigate1();

  if (sim.active) {
    setInterval(SIM_MOVE_INDEX);
    setInterval(SIM_PRINT_INDEX);
  }

  smartDelay(0); //read and process all serial inputs (except Iridium - it's read in the running function)

  #ifdef SERIAL_DEBUG
    readcmd();
  #endif

  if (cancel_iridium) {
    debugln(F(">>> CANCELLING IRIDIUM TRANSMISSION, SETTING NEXT INTERVAL TO URGENT"));
    intervals[IR_INDEX] = IR_URGENT_INTERVAL;
    return false;
  }
  else
    return true;
}

void navigate1() {
  if (warning()) { //watchdog shutdown warning => rudder straight and do not navigate
    rudder.pulse = 100;
    return;
  }
  
  if (sim.active) { //simulation
    nav.trueHeading = sim.trueHeading;
    nav.trueWind = sim.trueWind;
    nav.gps = sim.gps;
    navigate();
  }
  else { //real, not simulation
    //initialize magnetic declination if not initialized
    if (!nav.magDecInitialized && gps.location.isValid() && gps.hdop.isValid() && gps.hdop.value()/100 < GPS_HDOP_THRESHOLD) {
      updateMagDeclination({gps.location.lat(), gps.location.lng()}); //also updates nav.magDecInitialized

      //fix next waypoint if EEPROM checksum failed at startup
      if (ee.checksum_failed) {
        ee.checksum_failed = false;
        ee.nextWaypoint = failsafeWaypoint_West2East(); //valid GPS needed
        eeSave(SAVE_REASON_FAILSAFE_WAYPOINT);
      }
    }

    if (nav.mode != NAVMODE_MANUAL && sail.windUpdated && gps.location.isValid() && nav.magDecInitialized) {
      nav.trueHeading = mod360(round(compass.yaw + nav.magDec)); //degs
      nav.trueWind = mod360(nav.trueHeading + windFusion(sail.relWind, anemo.direction)); //degs
      nav.gps = {gps.location.lat(), gps.location.lng()};
      navigate();
    }
  }
}

static void smartDelay(unsigned long ms)
{
  unsigned long start = millis();
  do {
    readAllSerial();
  } while (millis() - start < ms);
}

void readAllSerial() {
  while (Serial1.available()) { //hall sensor
    char c = Serial1.read();
    //debugWrite(c); //debug raw output
    hallObj.encode(c);
    if (hall.isValid() && hall.isUpdated())
      sail.hall_update = millis();
      sail.angle = (360 - atoi(hall.value()) + 360) % 360; //hall returns positive angle to the left, we want it like the compass
      sail.relWind = REL_WIND(sail.angle, (int)ee.last_A - 100);
      sail.windUpdated = true;
  }

  while (Serial2.available()) { //compass sensor
    char c = Serial2.read();
    //debugWrite(c); //debug raw output
    compassObj.encode(c);
    if (compass_ID.isValid() && compass_ID.isUpdated()
    && compass_yaw.isValid() && compass_yaw.isUpdated()) {
      compass.ID = atof(compass_ID.value());
      compass.yaw = atof(compass_yaw.value());
      compass.pitch = atof(compass_pitch.value());
      compass.roll = atof(compass_roll.value());
      compass.temp = atof(compass_temp.value());
    }
  }
  
  if(Serial3.available()) {
    switch (mux) {
      case MUX_GPS:
        while (Serial3.available())
          gps.encode(Serial3.read());
        break;
        
      case MUX_ACT:
        while (Serial3.available()) {
          char c = Serial3.read();
          //debugWrite(c); //debug raw output: ActuatorTX
          actObj.encode(c);
        }
        
        if (sail_A.isValid() && sail_A.isUpdated()) { //command to move the actuator was received
          if (sail_state == SAIL_STATE_WAIT_A) {
            sail_state = SAIL_STATE_NEW_A;
          }

          sail_start_ms = millis();
          //sail_A.value() is read when P/E is received
       
          debugln();
          debug(F("SAILWING RESPONSE: Actuator: "));
          debugln(sail_A.value());
        }
        
        if (sail_P.isValid() && sail_P.isUpdated()) {
          if (sail_state == SAIL_STATE_WAIT_PE) {
            sail_state = SAIL_STATE_NEW_P;
            actAddTime(millis(), false); //runs just once to avoid duplicates from multiple 'P' responses, do not save as eeSave() follows
          }
            
          sail_start_ms = millis();
          act.last_P = (unsigned int)atoi(sail_P.value());
          ee.last_A = (unsigned int)atoi(sail_A.value());
          eeSave(SAVE_REASON_LASTAP);
          sail.relWind = REL_WIND(sail.angle, (int)ee.last_A - 100);
          sail.windUpdated = true;
          
          debugln();
          debug(F("SAILWING RESPONSE: Potentiometer: "));
          debugln(sail_P.value());

        }
        
        if (sail_E.isValid() && sail_E.isUpdated()) {
          if (sail_state == SAIL_STATE_WAIT_PE) {
            sail_state = SAIL_STATE_NEW_E;
            actAddTime(millis(), false); //runs just once to avoid duplicates from multiple 'E' responses, do not save as eeSave() follows
          }
            
          sail_start_ms = millis();
          act.last_E = (unsigned int)atoi(sail_E.value());
          ee.last_A = (unsigned int)atoi(sail_A.value());
          eeSave(SAVE_REASON_LASTAE);
          sail.relWind = REL_WIND(sail.angle, (int)ee.last_A - 100);
          sail.windUpdated = true;
          
          debugln();
          debug(F("SAILWING RESPONSE: Encoder: "));
          debugln(sail_E.value());
        }
        
        if (sail_bat.isValid() && sail_bat.isUpdated()) {
          //new data ends with T
          sail_start_ms = millis();
          data2.sail_vaB = decodeVamps((unsigned int)atoi(sail_bat.value()), 10, 10);

          debugln();
          debug(F("SAILWING RESPONSE: Battery: "));
          debugln((unsigned int)atoi(sail_bat.value()));
        }
        
        if (sail_panelR.isValid() && sail_panelR.isUpdated()) {
          //new data ends with T
          sail_start_ms = millis();
          data2.sail_vaR = decodeVamps((unsigned int)atoi(sail_panelR.value()), 10, 1);

          debugln();
          debug(F("SAILWING RESPONSE: Right Panel: "));
          debugln((unsigned int)atoi(sail_panelR.value()));
        }
        
        if (sail_panelL.isValid() && sail_panelL.isUpdated()) {
          //new data ends with T
          sail_start_ms = millis();
          data2.sail_vaL = decodeVamps((unsigned int)atoi(sail_panelL.value()), 10, 1);

          debugln();
          debug(F("SAILWING RESPONSE: Left Panel: "));
          debugln((unsigned int)atoi(sail_panelL.value()));
        }
        
        if (sail_temp.isValid() && sail_temp.isUpdated()) {
          if (sail_state == SAIL_STATE_WAIT_DATA)
            sail_state = SAIL_STATE_NEW_DATA; //received T => that's all data
          data2.last_saildata_update = millis();
          
          sail_start_ms = millis();
          data2.sail_temp = atof(sail_temp.value());

          debugln();
          debug(F("SAILWING RESPONSE: Temp: "));
          debugln(sail_temp.value());
        }
        break;
        
      case MUX_AIS:
        while (Serial3.available()) {
          char c = Serial3.read();
          //debugWrite(c); //debug raw output: AIS
        }
        break;
        
      default:
        break;
    }
  }

  readCamCmd(); //camSerial

  while (anemoSerial && anemoSerial.available()) {
    char c = anemoSerial.read();
    //debugWrite(c); //debug raw output: anemo
    anemoObj.encode(c);

    if (anemoDirection.isValid() && anemoDirection.isUpdated())
      anemo.direction = atof(anemoDirection.value());

    if (anemoSpeed.isValid() && anemoSpeed.isUpdated())
      anemo.speed = atof(anemoSpeed.value());
  }
  
  while (rudderSerial && rudderSerial.available()) {
    char c = rudderSerial.read();
    rudder.feedback = c;
    rudder.count++;
    rudder.last_update = millis();

    debugWrite(c); //debug raw output: rudder feedback
  }
}

void checkSailResponse() {
  if (sail_state == SAIL_STATE_NEW_DATA) {
    debugln(F("SAILWING DATA RECEIVED."));
    sail_state = SAIL_STATE_IDLE;
    digitalWrite(ACT_ON, LOW);
    switchGPS();
    if (saildata_callback_success != NULL)
      saildata_callback_success();
  }
  else if (sail_state == SAIL_STATE_WAIT_DATA && millis() > sail_start_ms + SAIL_TIMEOUT_DATA) {
    debugln(F("SAILWING DATA TIMEOUT, turning off ActuatorTX..."));
    sail_state = SAIL_STATE_IDLE;
    digitalWrite(ACT_ON, LOW);
    switchGPS();
    if (saildata_callback_timeout != NULL)
      saildata_callback_timeout();
  }
  else if (sail_state == SAIL_STATE_NEW_A) {
    debugln(F("SAILWING 'A' RECEIVED. WAITING FOR PE..."));
    sail_state = SAIL_STATE_WAIT_PE;
    sail_start_ms = millis();
  }
  else if (sail_state == SAIL_STATE_WAIT_A && millis() > sail_start_ms + SAIL_TIMEOUT_A
    || sail_state == SAIL_STATE_WAIT_PE && millis() > sail_start_ms + SAIL_TIMEOUT_PE) {
      
    sail_retries++;
    
    if (sail_retries > SAIL_MAX_RETRIES) {
      debugln(F("SAILWING 'A'/'PE' TIMEOUT, MAX RETRIES REACHED, entering wait mode, turning off ActuatorTX..."));
      sail_state = SAIL_STATE_IDLE;
      sail_max_retries_wait = true;  //will change to false after SAIL_WAIT_MAX_RETRIES_PERIOD has passed
      sail_max_retries_wait_ms = millis();
      digitalWrite(ACT_ON, LOW);
      switchGPS();
      sail_retries = 0;
    }
    else { //retrying
      debug(F("SAILWING 'A' TIMEOUT, retrying... ")); debug(sail_retries); debug("/"); debugln(SAIL_MAX_RETRIES);
      retryActuator();
    }
  }
  else if (sail_state == SAIL_STATE_NEW_P) {
    debugln(F("SAILWING 'P' RECEIVED, turning off ActuatorTX..."));
    sail_state = SAIL_STATE_IDLE;
    act.confirmed_PE = true;
    digitalWrite(ACT_ON, LOW);
    switchGPS();
  }
  else if (sail_state == SAIL_STATE_NEW_E) {
    debugln(F("SAILWING 'E' RECEIVED, turning off ActuatorTX..."));
    sail_state = SAIL_STATE_IDLE;
    act.confirmed_PE = true;
    digitalWrite(ACT_ON, LOW);
    switchGPS();
  }
  else if (sail_max_retries_wait && millis() > sail_max_retries_wait_ms + SAIL_MAX_RETRIES_WAIT_PERIOD) {
    debugln(F("SAILWING WAIT MODE ENDED, going idle..."));
    sail_max_retries_wait = false;
    sail_retries = 0;
  }
}

void heartbeat() {
  static char hb = LOW;
  hb = (hb == LOW) ? HIGH : LOW;
  digitalWrite(HEARTBEAT, hb);   
}

void ledBlink() {
  if (gps.location.isValid() && gps.location.lng() > BLINK_STOP_LNG_FROM && gps.location.lng() < BLINK_STOP_LNG_TO) { //do not blink in this interval
    digitalWrite(LED, LOW);
    digitalWrite(LED_EXT, LOW);
    return;
  }

  bool gps_ok = (gps.location.isValid() && gps.hdop.isValid() && gps.hdop.value()/100 < GPS_HDOP_THRESHOLD);
  
  if (mux == MUX_IR)
    blinkMode = BLINK_IRIDIUM;
  else if (mux == MUX_ACT)
    blinkMode = BLINK_ACT;
  else if (gps_ok && nav.magDecInitialized && headingOK(nav.error))
    blinkMode = BLINK_HEADING;
  else if (gps_ok)
    blinkMode = BLINK_GPS;
  else
    blinkMode = BLINK_STARTUP;

  static unsigned char pos = 0;
  static unsigned char counter = 0;
  static unsigned char state = LOW;

  if (state == LOW) {
    digitalWrite(LED, HIGH);
    digitalWrite(LED_EXT, HIGH);
    state = HIGH;
    intervals[BLINK_INDEX] = BLINK_ON_INTERVAL;
  }
  else {
    digitalWrite(LED, LOW);
    digitalWrite(LED_EXT, LOW);
    state = LOW;

    counter++;

    if (pos == 0 && counter >= lowByte(blinkMode)) {
      counter = 0;
      pos = 1;
      intervals[BLINK_INDEX] = BLINK_PAUSE2_INTERVAL;
    }
    else if (pos == 1 && counter >= highByte(blinkMode)) {
      counter = 0;
      pos = 0;
      intervals[BLINK_INDEX] = BLINK_PAUSE2_INTERVAL;
    }
    else
      intervals[BLINK_INDEX] = BLINK_PAUSE1_INTERVAL;
  }
}
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

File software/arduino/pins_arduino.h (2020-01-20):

/*
  pins_arduino.h - Pin definition functions for Arduino
  Part of Arduino - http://www.arduino.cc/

  Copyright (c) 2007 David A. Mellis

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
  You should have received a copy of the GNU Lesser General
  Public License along with this library; if not, write to the
  Free Software Foundation, Inc., 59 Temple Place, Suite 330,
  Boston, MA  02111-1307  USA
*/

#ifndef Pins_Arduino_h
#define Pins_Arduino_h

#include <avr/pgmspace.h>

#define NUM_DIGITAL_PINS            70
#define NUM_ANALOG_INPUTS           16
#define analogInputToDigitalPin(p)  ((p < 16) ? (p) + 54 : -1)
#define digitalPinHasPWM(p)         (((p) >= 2 && (p) <= 13) || ((p) >= 44 && (p)<= 46))

#define PIN_SPI_SS    (53)
#define PIN_SPI_MOSI  (51)
#define PIN_SPI_MISO  (50)
#define PIN_SPI_SCK   (52)

static const uint8_t SS   = PIN_SPI_SS;
static const uint8_t MOSI = PIN_SPI_MOSI;
static const uint8_t MISO = PIN_SPI_MISO;
static const uint8_t SCK  = PIN_SPI_SCK;

#define PIN_WIRE_SDA        (20)
#define PIN_WIRE_SCL        (21)

static const uint8_t SDA = PIN_WIRE_SDA;
static const uint8_t SCL = PIN_WIRE_SCL;

#define LED_BUILTIN 13

#define PIN_A0   (54)
#define PIN_A1   (55)
#define PIN_A2   (56)
#define PIN_A3   (57)
#define PIN_A4   (58)
#define PIN_A5   (59)
#define PIN_A6   (60)
#define PIN_A7   (61)
#define PIN_A8   (62)
#define PIN_A9   (63)
#define PIN_A10  (64)
#define PIN_A11  (65)
#define PIN_A12  (66)
#define PIN_A13  (67)
#define PIN_A14  (68)
#define PIN_A15  (69)

static const uint8_t A0 = PIN_A0;
static const uint8_t A1 = PIN_A1;
static const uint8_t A2 = PIN_A2;
static const uint8_t A3 = PIN_A3;
static const uint8_t A4 = PIN_A4;
static const uint8_t A5 = PIN_A5;
static const uint8_t A6 = PIN_A6;
static const uint8_t A7 = PIN_A7;
static const uint8_t A8 = PIN_A8;
static const uint8_t A9 = PIN_A9;
static const uint8_t A10 = PIN_A10;
static const uint8_t A11 = PIN_A11;
static const uint8_t A12 = PIN_A12;
static const uint8_t A13 = PIN_A13;
static const uint8_t A14 = PIN_A14;
static const uint8_t A15 = PIN_A15;

// A majority of the pins are NOT PCINTs, SO BE WARNED (i.e. you cannot use them as receive pins)
// Only pins available for RECEIVE (TRANSMIT can be on any pin):
// (I've deliberately left out pin mapping to the Hardware USARTs - seems senseless to me)
// Pins: 10, 11, 12, 13,  50, 51, 52, 53,  62, 63, 64, 65, 66, 67, 68, 69

#define digitalPinToPCICR(p)    ( (((p) >= 10) && ((p) <= 13)) || \
                                  (((p) >= 50) && ((p) <= 53)) || \
                                  (((p) >= 62) && ((p) <= 69)) ? (&PCICR) : ((uint8_t *)0) )

#define digitalPinToPCICRbit(p) ( (((p) >= 10) && ((p) <= 13)) || (((p) >= 50) && ((p) <= 53)) ? 0 : \
                                ( (((p) >= 62) && ((p) <= 69)) ? 2 : \
                                0 ) )

#define digitalPinToPCMSK(p)    ( (((p) >= 10) && ((p) <= 13)) || (((p) >= 50) && ((p) <= 53)) ? (&PCMSK0) : \
                                ( (((p) >= 62) && ((p) <= 69)) ? (&PCMSK2) : \
                                ((uint8_t *)0) ) )

#define digitalPinToPCMSKbit(p) ( (((p) >= 10) && ((p) <= 13)) ? ((p) - 6) : \
                                ( ((p) == 50) ? 3 : \
                                ( ((p) == 51) ? 2 : \
                                ( ((p) == 52) ? 1 : \
                                ( ((p) == 53) ? 0 : \
                                ( (((p) >= 62) && ((p) <= 69)) ? ((p) - 62) : \
                                0 ) ) ) ) ) )

#define digitalPinToInterrupt(p) ((p) == 2 ? 0 : ((p) == 3 ? 1 : ((p) >= 18 && (p) <= 21 ? 23 - (p) : NOT_AN_INTERRUPT)))

#ifdef ARDUINO_MAIN

const uint16_t PROGMEM port_to_mode_PGM[] = {
	NOT_A_PORT,
	(uint16_t) &DDRA,
	(uint16_t) &DDRB,
	(uint16_t) &DDRC,
	(uint16_t) &DDRD,
	(uint16_t) &DDRE,
	(uint16_t) &DDRF,
	(uint16_t) &DDRG,
	(uint16_t) &DDRH,
	NOT_A_PORT,
	(uint16_t) &DDRJ,
	(uint16_t) &DDRK,
	(uint16_t) &DDRL,
};

const uint16_t PROGMEM port_to_output_PGM[] = {
	NOT_A_PORT,
	(uint16_t) &PORTA,
	(uint16_t) &PORTB,
	(uint16_t) &PORTC,
	(uint16_t) &PORTD,
	(uint16_t) &PORTE,
	(uint16_t) &PORTF,
	(uint16_t) &PORTG,
	(uint16_t) &PORTH,
	NOT_A_PORT,
	(uint16_t) &PORTJ,
	(uint16_t) &PORTK,
	(uint16_t) &PORTL,
};

const uint16_t PROGMEM port_to_input_PGM[] = {
	NOT_A_PIN,
	(uint16_t) &PINA,
	(uint16_t) &PINB,
	(uint16_t) &PINC,
	(uint16_t) &PIND,
	(uint16_t) &PINE,
	(uint16_t) &PINF,
	(uint16_t) &PING,
	(uint16_t) &PINH,
	NOT_A_PIN,
	(uint16_t) &PINJ,
	(uint16_t) &PINK,
	(uint16_t) &PINL,
};
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

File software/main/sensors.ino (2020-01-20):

vamps read_INA(Adafruit_INA219 ina) {
  float shuntvoltage = ina.getShuntVoltage_mV();
  float busvoltage = ina.getBusVoltage_V();
  float volts = busvoltage + shuntvoltage / 1000;

  if (volts < 0 || volts > MAX_VALID_VOLTS)
    return {0, 0};
  
  float ma = ina.getCurrent_mA();
  return {volts, ma};
}

float readTemp(){
  byte data[12];
  byte addr[8];

  if (!ds.search(addr)) {
    //debug("No more addresses.\n");
    //no more sensors on chain, reset search
    ds.reset_search();
    return -1000;
  }
/*
  debug("R=");
  for( int i = 0; i < 8; i++) {
    debug(addr[i], HEX);
    debug(" ");
  }
*/
  if (OneWire::crc8( addr, 7) != addr[7]) {
    //debugln("CRC is not valid!");
    return -1000;
  }

  if (addr[0] != 0x10 && addr[0] != 0x28) {
    //debug("Device is not recognized");
    return -1000;
  }

  ds.reset();
  ds.select(addr);
  ds.write(0x44,1); // start conversion, with parasite power on at the end
  smartDelay(1000); //sometimes garbage result if this delay is missing
  byte present = ds.reset();
  ds.select(addr);  
  ds.write(0xBE); // Read Scratchpad

 
  for (int i = 0; i < 9; i++) { // we need 9 bytes
   data[i] = ds.read();
  }
 
  byte MSB = data[1];
  byte LSB = data[0];

  float tempRead = ((MSB << 8) | LSB); //using two's compliment
  float TemperatureSum = tempRead / 16;
 
  return TemperatureSum;
}

void BME_init() {
  bool status = bme.begin();
  if (!status) {
    debugln(F("Could not find a valid BME280 sensor, check wiring!"));
  } else {
    debugln(F("BME found."));
  }
}

void MPU_init() {
  mpu.init(true);

  uint8_t wai = mpu.whoami();

  if (wai == 0x71){
    debugln(F("MPU Successful connection"));
  }
  else{
    debug(F("MPU Failed connection: "));
    debugln2(wai, HEX);
  }
  
  uint8_t wai_AK8963 = mpu.AK8963_whoami();
  if (wai_AK8963 == 0x48){
    debugln(F("MPU Successful connection to mag"));
  }
  else{
    debug(F("MPU Failed connection to mag: "));
    debugln2(wai_AK8963, HEX);
  }

  mpu.calib_acc();
  mpu.calib_mag(); 
}

void print_vamps(vamps va) {
  debug(va.volts);
  debug("V ");
  debug(va.mamps);
  debug("mA");
}

void readFlood() {
  #define MAX_MEASUREMENTS 10000

  if (data2.flood0_total > MAX_MEASUREMENTS)
    data2.flood0_total = data2.flood0_count = 0;
  
  data2.flood0 = analogRead(FLOOD0);

  if (data2.flood0 < FLOOD_THRESHOLD)
    data2.flood0_count++;

  data2.flood0_total++;

  if (data2.flood1_total > MAX_MEASUREMENTS)
    data2.flood1_total = data2.flood1_count = 0;
  
  data2.flood1 = analogRead(FLOOD1);

  if (data2.flood1 < FLOOD_THRESHOLD)
    data2.flood1_count++;

  data2.flood1_total++;
}

vamps decodeVamps(unsigned int val, float volts_factor, float mamps_factor) {
  vamps ret;
  ret.volts = ((val >> 8) & 0xFF) / volts_factor;
  ret.mamps = (val & 0xFF) / mamps_factor;
  return ret;
}
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

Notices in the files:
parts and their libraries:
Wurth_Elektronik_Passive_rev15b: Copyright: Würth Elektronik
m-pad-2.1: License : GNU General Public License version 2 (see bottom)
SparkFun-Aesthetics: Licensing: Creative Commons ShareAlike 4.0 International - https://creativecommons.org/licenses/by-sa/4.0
